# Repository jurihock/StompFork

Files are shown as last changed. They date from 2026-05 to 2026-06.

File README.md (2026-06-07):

# StompFork

This project is about an active audio signal splitter that utilizes the TL074 opamp to drive multiple parallel stompboxes.

## Key features

- Split one line-level input into three outputs
- Direct output (unity from input buffer)
- Stompbox output 1 (level pot + output buffer)
- Stompbox output 2 (level pot + output buffer)

## Power supply

- Recommended 18 V
- Should work at 12 V
- May work at 9 V
- Series schottky protection included

## Impedance

- Hi‑Z input (~1 MΩ AC)
- Lo‑Z output (~100 Ω AC)

## Caps

Depending on your preference, you can use polarized electrolytic caps in the signal path, or you can replace them with "audiophile" film caps. For this purpose, the KiCad project includes larger footprints for `C1` and `C5-C7`. 

If you decide to use the polarized electrolytic caps, ensure that the anode `+` is facing the opamp and the cathode `-` is facing the jacks.

Either way be sure to pick a sufficient voltage rating, e.g. 50 V.

## PCB

The circuit should fit on a standard 100x50 mm perfboard. You can save even more space by combining several smaller JST connectors into one larger one.

## Similar projects

- [The Splitter Kit](https://musikding.de/The-Splitter-kit) by [Das Musikding](https://musikding.de)
- [Signal Splitter](https://guitar-electronics.eu/en_US/c/SIGNAL-SPLITTER/68) by [Guitar Electronics](https://guitar-electronics.eu)

## Further reading

- [Designing With Opamps](https://sound-au.com/dwopa.htm) by [Rod Elliott](https://sound-au.com)

## Example build

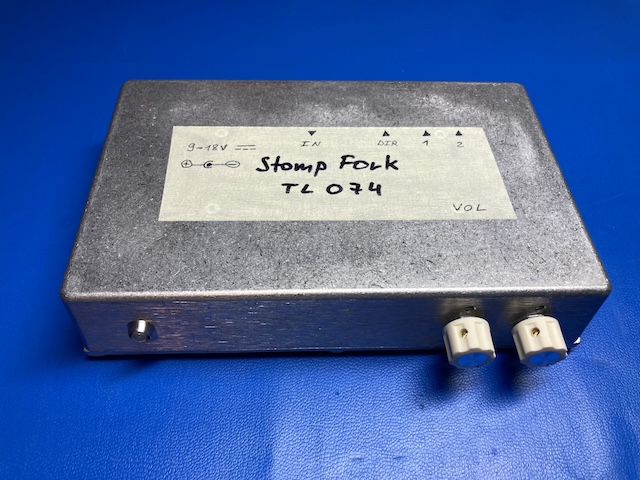
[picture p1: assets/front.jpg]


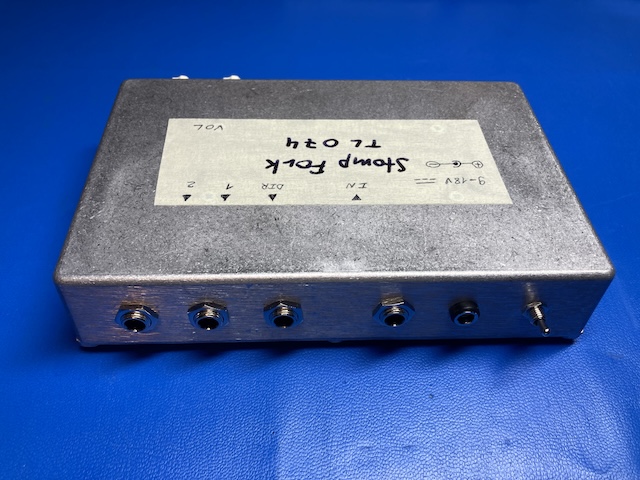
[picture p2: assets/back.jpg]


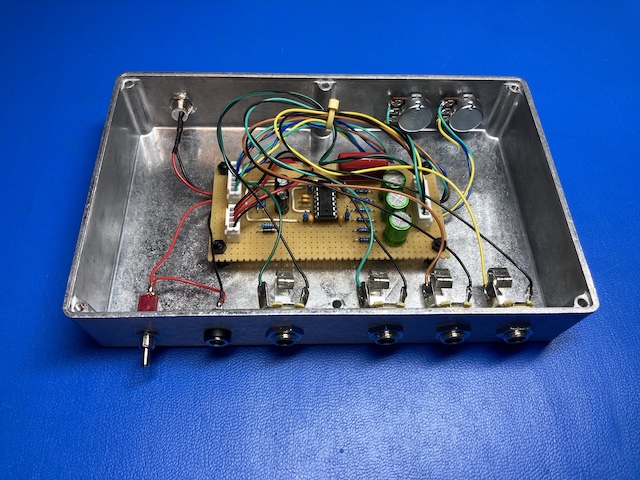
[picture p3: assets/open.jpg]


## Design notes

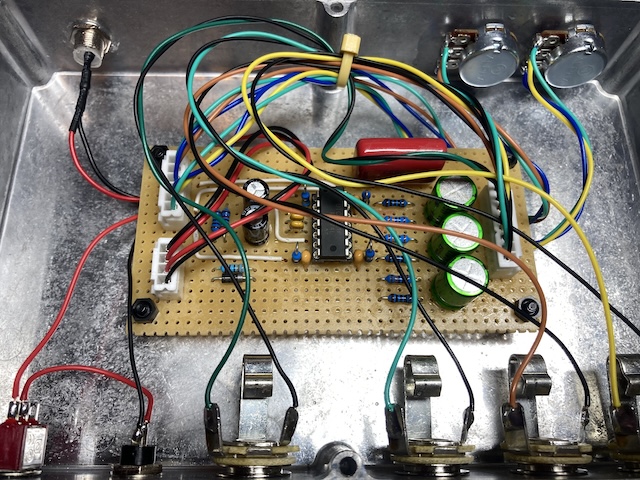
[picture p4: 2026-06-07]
assets/close.jpg

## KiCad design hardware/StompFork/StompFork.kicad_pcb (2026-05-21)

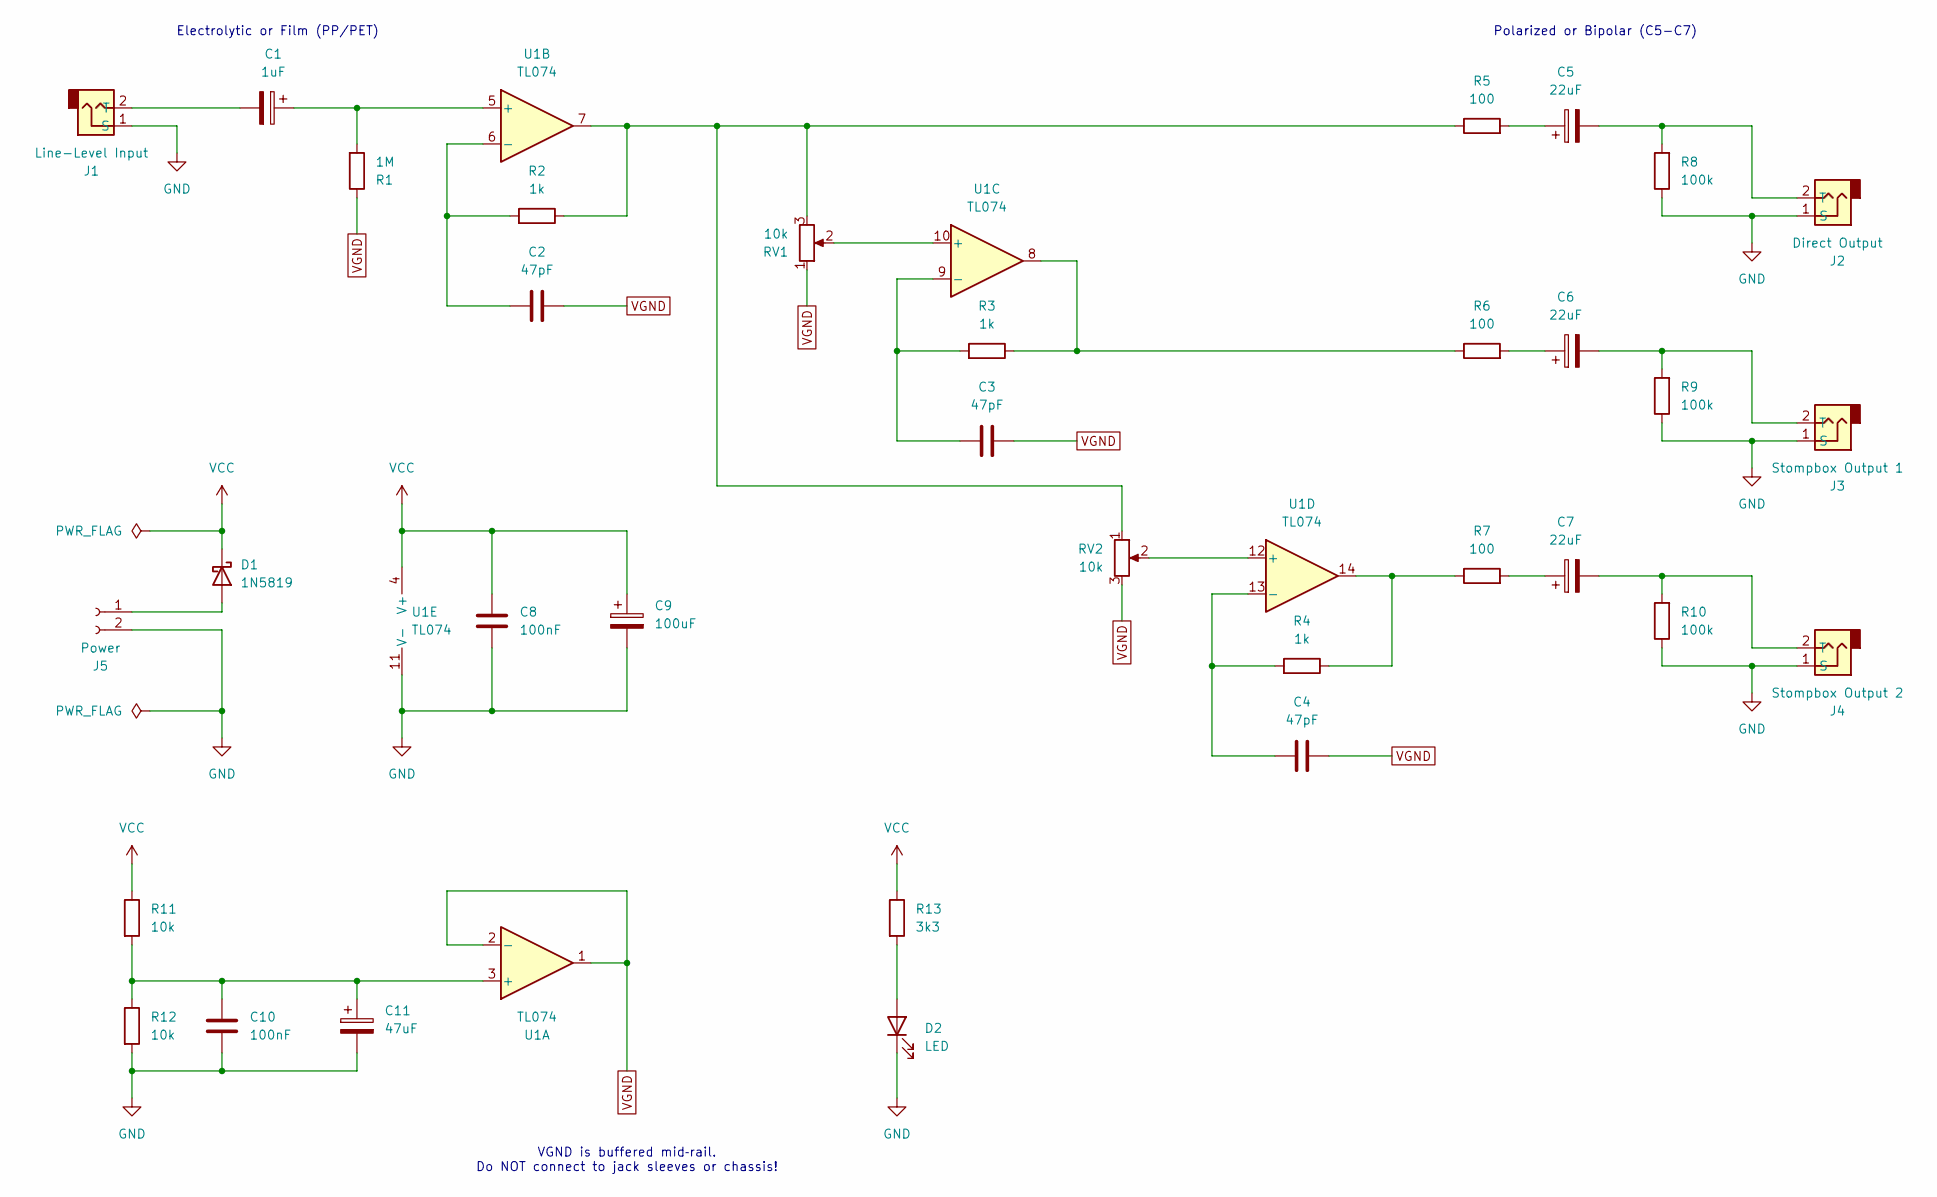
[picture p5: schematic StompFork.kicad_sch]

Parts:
C1: 1uF; CP_Axial_L18.0mm_D8.0mm_P25.00mm_Horizontal
C2, C3, C4: 47pF; C_Disc_D5.0mm_W2.5mm_P5.00mm
C5, C6, C7: 22uF; CP_Radial_D10.0mm_P5.00mm
C8, C10: 100nF; C_Disc_D5.0mm_W2.5mm_P5.00mm
C9: 100uF; CP_Radial_D6.3mm_P2.50mm
C11: 47uF; CP_Radial_D6.3mm_P2.50mm
D1: 1N5819; D_DO-41_SOD81_P10.16mm_Horizontal
D2: LED; JST_EH_B2B-EH-A_1x02_P2.50mm_Vertical
J1: Line-Level Input; JST_EH_B2B-EH-A_1x02_P2.50mm_Vertical
J2: Direct Output; JST_EH_B2B-EH-A_1x02_P2.50mm_Vertical
J3: Stompbox Output 1; JST_EH_B2B-EH-A_1x02_P2.50mm_Vertical
J4: Stompbox Output 2; JST_EH_B2B-EH-A_1x02_P2.50mm_Vertical
J5: Power; JST_EH_B2B-EH-A_1x02_P2.50mm_Vertical
R1: 1M; R_Axial_DIN0207_L6.3mm_D2.5mm_P2.54mm_Vertical
R2, R3, R4: 1k; R_Axial_DIN0207_L6.3mm_D2.5mm_P2.54mm_Vertical
R5, R6, R7: 100; R_Axial_DIN0207_L6.3mm_D2.5mm_P10.16mm_Horizontal
R8, R9, R10: 100k; R_Axial_DIN0207_L6.3mm_D2.5mm_P10.16mm_Horizontal
R11, R12: 10k; R_Axial_DIN0207_L6.3mm_D2.5mm_P10.16mm_Horizontal
R13: 3k3; R_Axial_DIN0207_L6.3mm_D2.5mm_P10.16mm_Horizontal
RV1, RV2: 10k; JST_EH_B3B-EH-A_1x03_P2.50mm_Vertical
U1: TL074; DIP-14_W7.62mm_Socket

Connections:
GND: C8.2, C9.2, C10.2, C11.2, D2.1 (K), J1.1 (S), J2.1 (S), J3.1 (S), J4.1 (S), J5.2, R8.1, R9.1, R10.1, R12.2, U1.11 (V-)
unnamed: C5.1, R5.2
unnamed: C6.1, R6.2
unnamed: C7.1, R7.2
unnamed: D1.2 (A), J5.1
unnamed: D2.2 (A), R13.2
unnamed: C1.2, J1.2 (T)
unnamed: C5.2, J2.2 (T), R8.2
unnamed: C6.2, J3.2 (T), R9.2
unnamed: C7.2, J4.2 (T), R10.2
unnamed: R2.1, R5.1, RV1.3, RV2.1, U1.7
unnamed: R3.1, R6.1, U1.8
unnamed: R4.1, R7.1, U1.14
unnamed: C10.1, C11.1, R11.2, R12.1, U1.3 (+)
unnamed: C1.1, R1.2, U1.5 (+)
unnamed: C2.1, R2.2, U1.6 (-)
unnamed: RV1.2, U1.10 (+)
unnamed: C3.1, R3.2, U1.9 (-)
unnamed: RV2.2, U1.12 (+)
unnamed: C4.1, R4.2, U1.13 (-)
VCC: C8.1, C9.1, D1.1 (K), R11.1, R13.1, U1.4 (V+)
VGND: C2.2, C3.2, C4.2, R1.1, RV1.1, RV2.3, U1.1, U1.2 (-)

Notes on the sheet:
Electrolytic or Film (PP/PET)
VGND is buffered mid‑rail. Do NOT connect to jack sleeves or chassis!
Polarized or Bipolar (C5-C7)

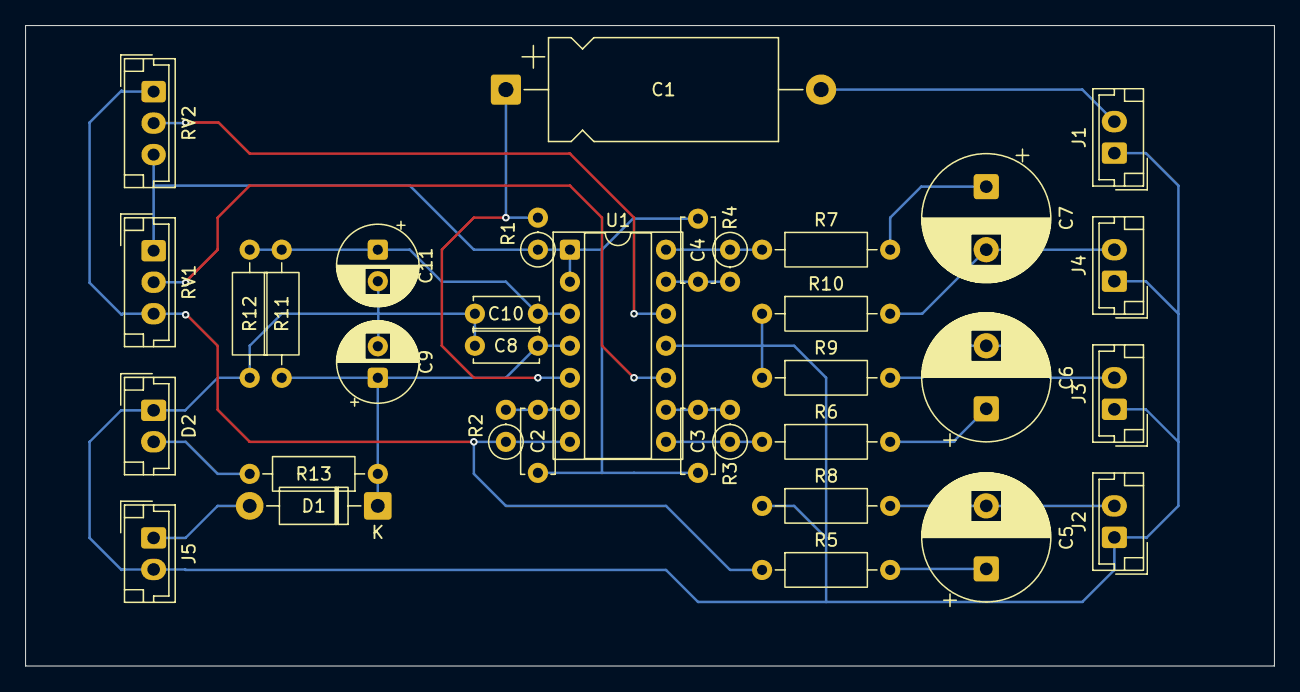
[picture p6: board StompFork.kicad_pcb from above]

Board: 2 copper layers, 99.1 x 50.8 mm, 34 parts (0 on the bottom side), 22 nets.

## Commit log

2026-05-17 Create KiCad project
    [StompFork.kicad_pcb, StompFork.kicad_sch]
2026-05-17 Create sketch using unity buffers
    [StompFork.kicad_sch]
2026-05-17 Add protection diode
    [StompFork.kicad_sch]
2026-05-17 Fix feedback paths
    [StompFork.kicad_sch]
2026-05-17 Polish schematic
    [StompFork.kicad_sch]
2026-05-17 Update specs
    [StompFork.kicad_sch]
2026-05-18 Fix typos
    [StompFork.kicad_sch]
2026-05-18 Fix part number order
    [StompFork.kicad_sch]
2026-05-18 Update power supply and impedance sections in README
2026-05-19 Update PCB
    [StompFork.kicad_pcb, StompFork.kicad_sch]
2026-05-20 Add status LED
    [StompFork.kicad_pcb, StompFork.kicad_sch]
2026-05-20 Fix VGND label placement
    [StompFork.kicad_sch]
2026-05-20 Update comments
    [StompFork.kicad_pcb, StompFork.kicad_sch]
2026-05-20 Update labels
    [StompFork.kicad_pcb]
2026-05-21 Fix cap footprints
    [StompFork.kicad_pcb, StompFork.kicad_sch]
